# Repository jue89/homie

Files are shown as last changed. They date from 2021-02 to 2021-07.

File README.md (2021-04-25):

# Homie

Homie is an attempt to create wired smart-home devices.
Those devices are connected using [DOSE](https://api.riot-os.org/group__drivers__dose.html).

## Bus Interface

Every device has two *4P4C* jacks. This enables daisy-chaining the devices into one serial bus. The first and last device have to be terminated using a 120Ω resistor.

The bus interface:

| Pin | Description |
| --- | --- |
| 1 | GND |
| 2 | CAN LOW |
| 3 | CAN HIGH |
| 4 | +5V |

## Debug Interface

The debug interface features:
- Accessing board RESET and BOOT selector line
- Debug UART
- SWD Interface
- Power supply

The pin layout is designed to tolerate wrongly-connected pin header.

All data lines (SWDIO, SWCLK, RX, TX) hat to be protected against short-circuit on the debug port. (E.g. series resistors, ...)

| Description | Name  | Pin | Pin | Name  | Description |
| --- | :---: | :----: | :----: | :---: | --- |
| Selectes the boot mode. Pulled with a on-board resistor to the right level. | BOOT  |  **1** | **2**  | RX | Debug UART RX (Debug Adapter -> Board) |
| Voltage for all IO pins | VIO |  **3** | **4**  | TX | Debug UART TX (Board -> Debug Adapter) |
| | NC |  **5** | **6**  | VIN | Supply for the borad. The debug adapter has to protect this current direct using a diode. |
| SWD data line | SWDIO |  **7** | **8**  | SWCLK | SWD clock line |
| Board reset. Low active. | RESET |  **9** | **10** | GND | Ground |

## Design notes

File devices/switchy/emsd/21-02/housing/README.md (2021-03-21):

# Switchy Housing

This folder contains two versions of the housing:
- 3 switches
- 5 switches

Beside the PCB, you'll need to add:
- 3x or 5x switches with 16mm diameter and 3V LED
- 2x M3x2.7mm threaded inserts (eg. [3D Jake](https://www.3djake.de/3djake/gewindeeinsaetze-50er-set?sai=9419))
- 2x M3x10mm countersunk screw (eg. [Reichelt](https://www.reichelt.de/flach-senkkopfschrauben-kreuzschlitz-pzd-m3-10-mm-sks-m3x10-50-p65747.html))

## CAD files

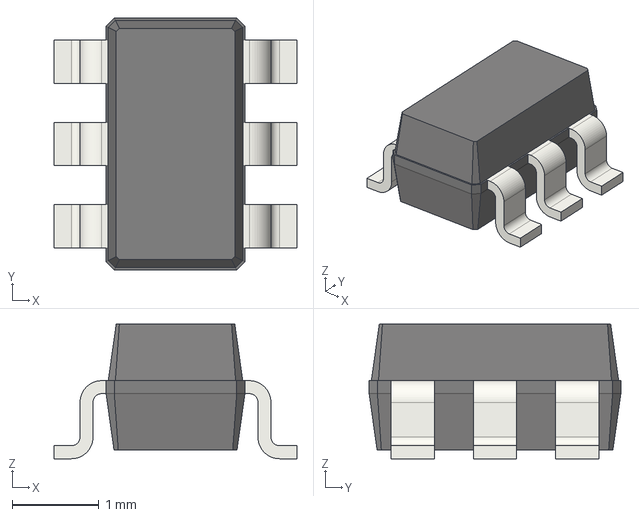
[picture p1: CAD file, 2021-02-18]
devices/flowr/pcb-iface/pool/3d_models/cache/6d752bc3-29b3-45df-8cf2-1e3aacefbcc6/3d_models/ic/so/SOT-23-6.step
2.80 x 2.90 x 1.55 mm

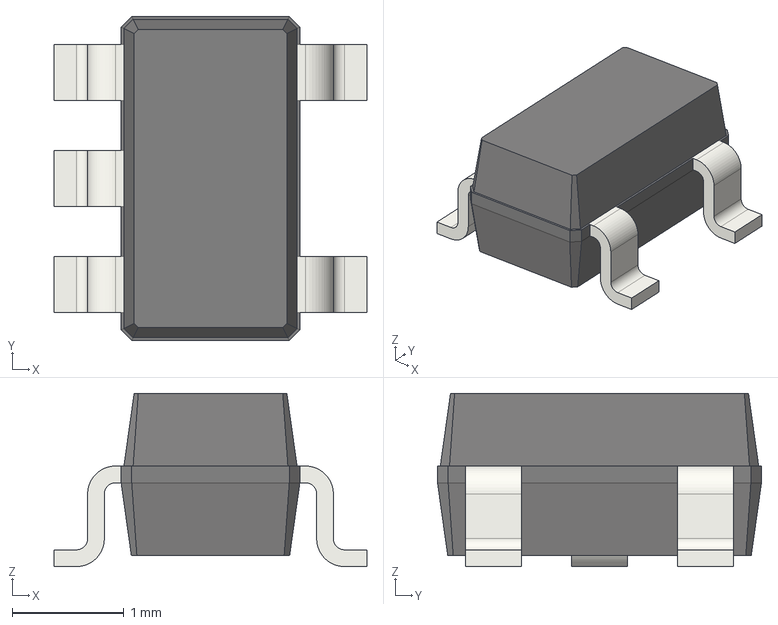
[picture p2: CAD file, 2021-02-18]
devices/flowr/pcb-iface/pool/3d_models/cache/6d752bc3-29b3-45df-8cf2-1e3aacefbcc6/3d_models/ic/SOT-23-5.step
2.80 x 2.90 x 1.55 mm

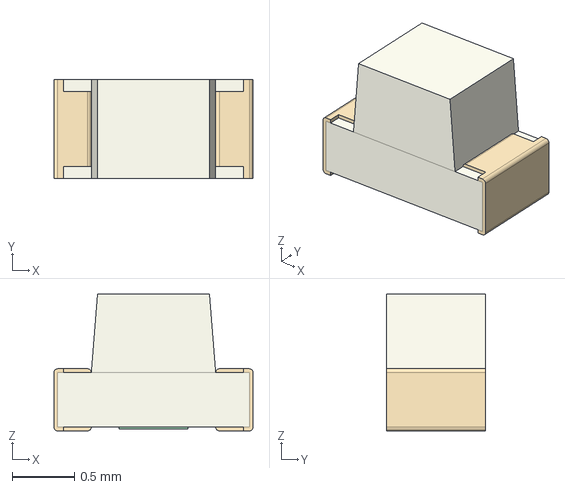
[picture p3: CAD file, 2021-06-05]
devices/flowr/pcb-iface/pool/3d_models/cache/6d752bc3-29b3-45df-8cf2-1e3aacefbcc6/3d_models/opto/LED_0603_1608Metric.step
1.60 x 0.8 x 1.10 mm

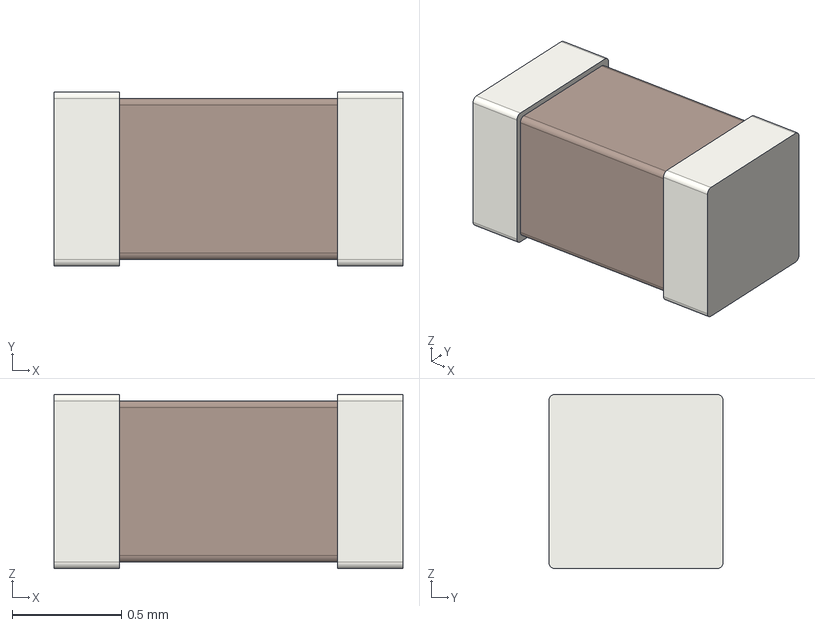
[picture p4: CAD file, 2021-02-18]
devices/flowr/pcb-iface/pool/3d_models/cache/6d752bc3-29b3-45df-8cf2-1e3aacefbcc6/3d_models/passive/capacitor/C_0603_1608Metric.step
1.60 x 0.8 x 0.8 mm

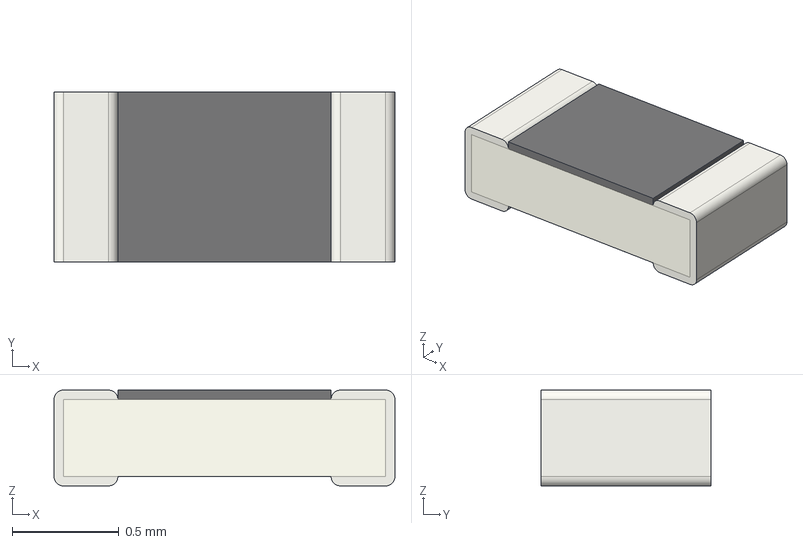
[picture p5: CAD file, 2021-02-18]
devices/flowr/pcb-iface/pool/3d_models/cache/6d752bc3-29b3-45df-8cf2-1e3aacefbcc6/3d_models/passive/resistor/R_0603_1608Metric.step
1.60 x 0.8 x 0.45 mm

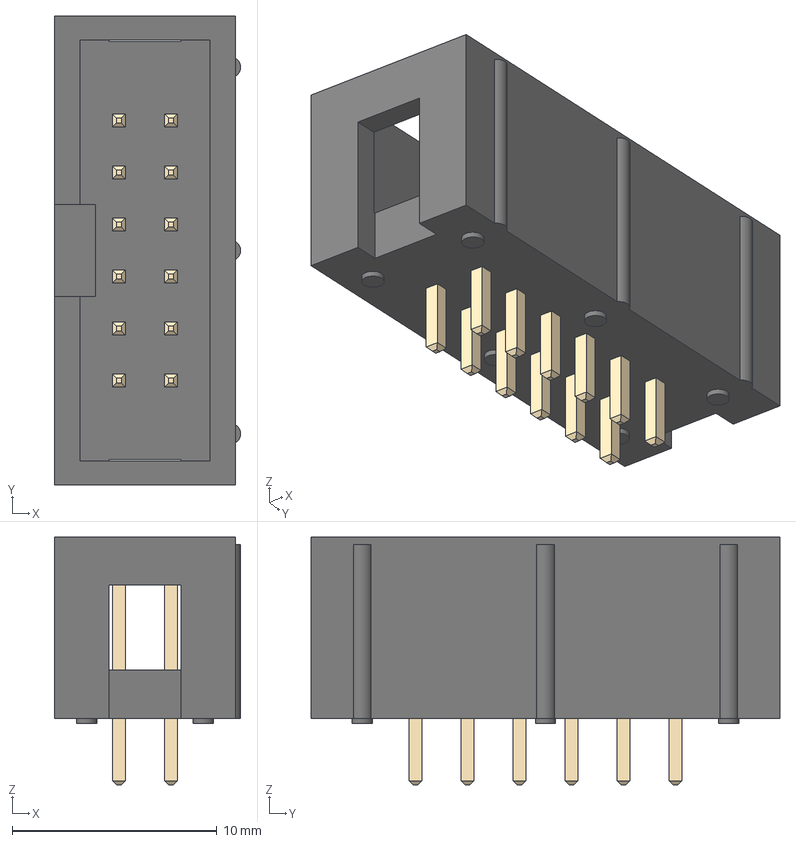
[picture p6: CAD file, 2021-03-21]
devices/picap/pcb/pool/3d_models/cache/6d752bc3-29b3-45df-8cf2-1e3aacefbcc6/3d_models/connector/header-idc/2.54mm/IDC-Header_2x06_P2.54mm_Vertical.step
9.10 x 22.9 x 12.1 mm

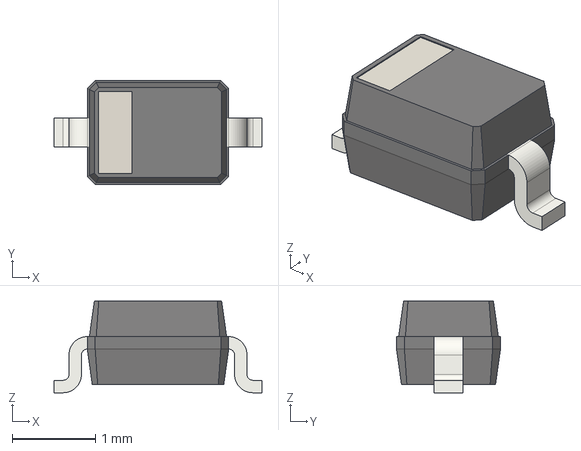
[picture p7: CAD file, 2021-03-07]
devices/relay/pcb/pool/3d_models/cache/6d752bc3-29b3-45df-8cf2-1e3aacefbcc6/3d_models/diode/D_SOD-323.step
2.50 x 1.25 x 1.10 mm

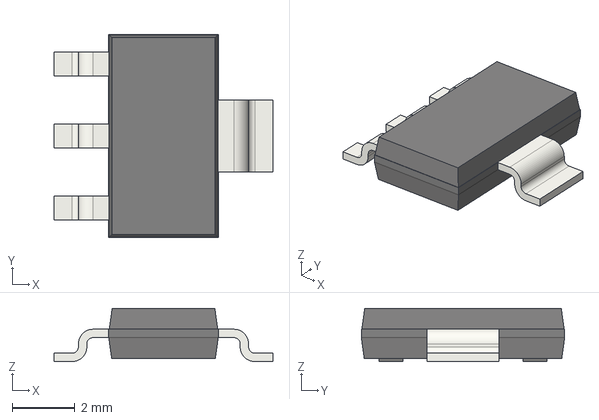
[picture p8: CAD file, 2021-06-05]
devices/relay/pcb/pool/3d_models/cache/6d752bc3-29b3-45df-8cf2-1e3aacefbcc6/3d_models/ic/so/SOT-223.step
7.00 x 6.50 x 1.70 mm

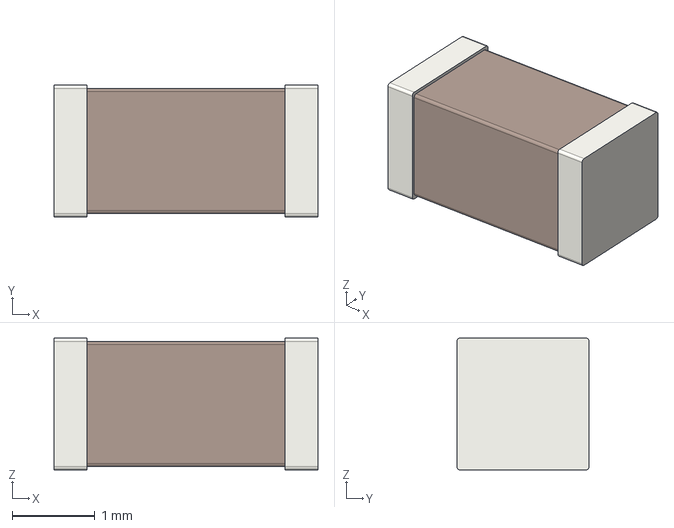
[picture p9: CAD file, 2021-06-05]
devices/relay/pcb/pool/3d_models/cache/6d752bc3-29b3-45df-8cf2-1e3aacefbcc6/3d_models/passive/capacitor/C_1206_3216Metric.step
3.20 x 1.60 x 1.60 mm

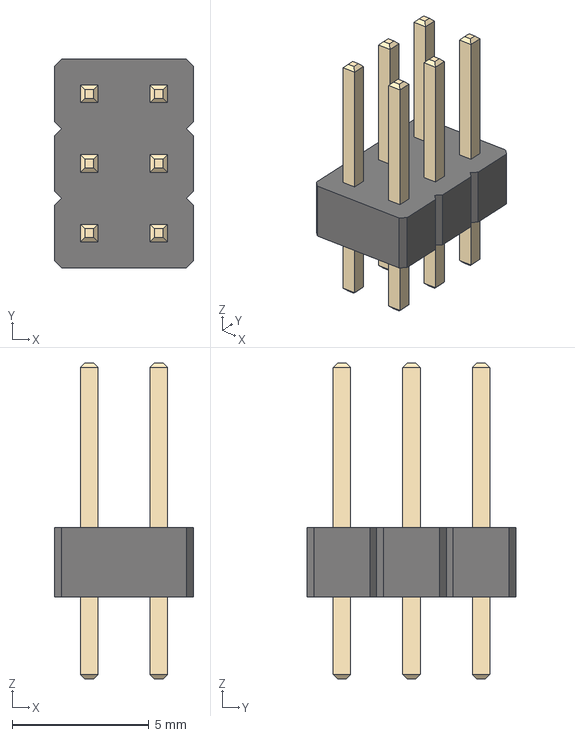
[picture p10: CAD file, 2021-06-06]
devices/switchy-rgb/pcb/pool/3d_models/cache/6d752bc3-29b3-45df-8cf2-1e3aacefbcc6/3d_models/connector/header/2.54mm/PinHeader_2x03_P2.54mm_Vertical.step
5.08 x 7.62 x 11.5 mm

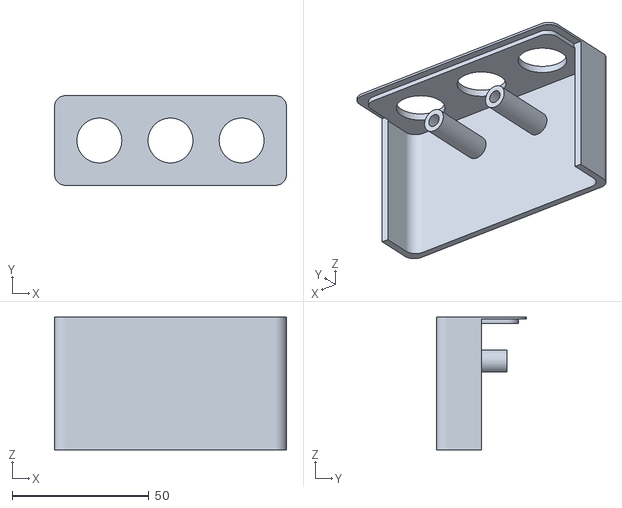
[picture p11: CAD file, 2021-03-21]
devices/switchy/emsd/21-02/housing/3front.stl
84.8 x 32.8 x 48.6

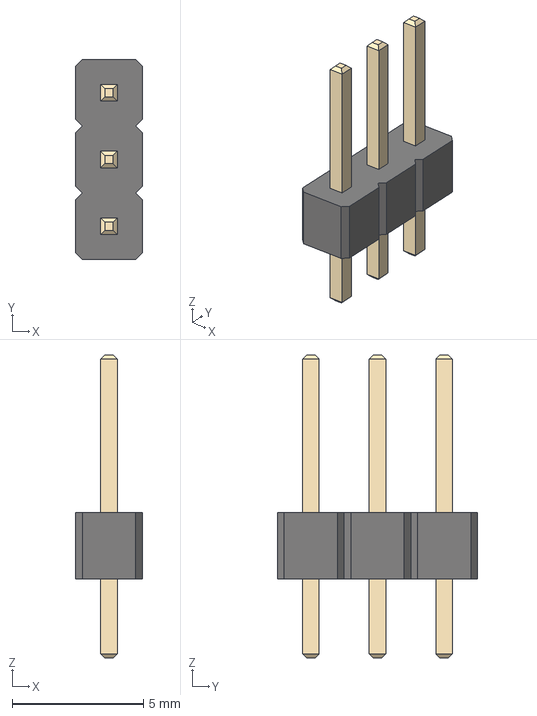
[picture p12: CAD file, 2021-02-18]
devices/switchy/pcb/pool/3d_models/cache/6d752bc3-29b3-45df-8cf2-1e3aacefbcc6/3d_models/connector/header/2.54mm/PinHeader_1x03_P2.54mm_Vertical.step
2.54 x 7.62 x 11.5 mm

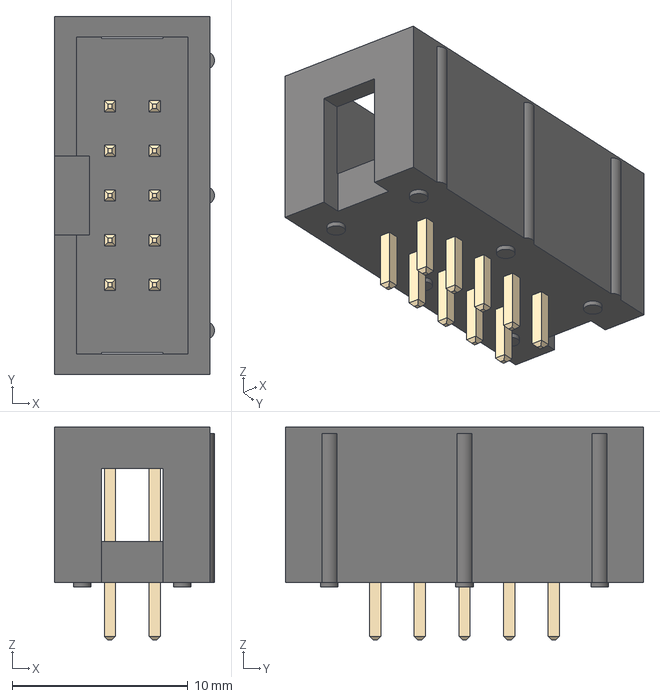
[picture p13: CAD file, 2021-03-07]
tools/prog/pcb/cache/3d_models/pool_6d752bc3-29b3-45df-8cf2-1e3aacefbcc6/3d_models/connector/header-idc/2.54mm/IDC-Header_2x05_P2.54mm_Vertical.step
9.10 x 20.4 x 12.1 mm

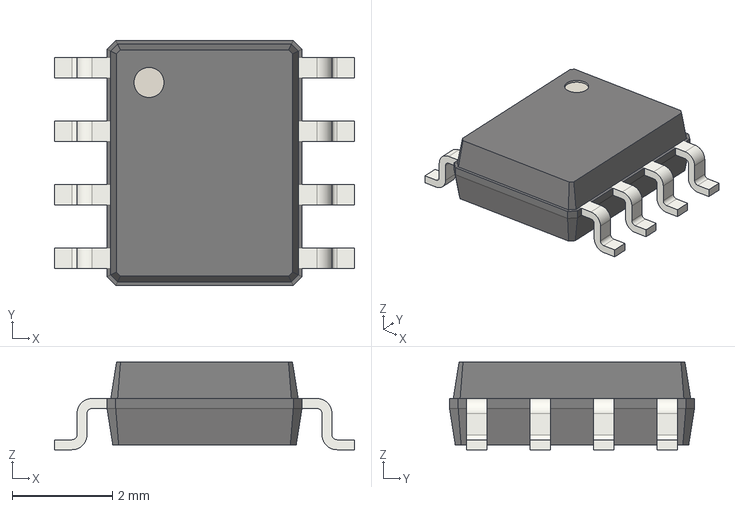
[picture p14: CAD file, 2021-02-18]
devices/flowr/pcb-iface/pool/3d_models/cache/6d752bc3-29b3-45df-8cf2-1e3aacefbcc6/3d_models/ic/so/SOIC-8_3.9x4.9mm_P1.27mm.step
6.00 x 4.90 x 1.75 mm

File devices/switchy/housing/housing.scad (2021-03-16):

$fn = 50;

module body (w, h, d) {
    radius = 4;
    linear_extrude (height = d, center = true) hull () {
        translate([w / 2 - radius, h / 2 - radius, 0]) circle(r = radius);
        translate([w / -2 + radius, h / 2 - radius, 0]) circle(r = radius);
        translate([w / 2 - radius, -h / 2 + radius, 0]) circle(r = radius);
        translate([w / -2 + radius, -h / 2 + radius, 0]) circle(r = radius);
    };
}

module half (h, w, d, wall, gap) {
    union() {
        difference () {
            // Outer shell
            body(w = w + 2 * wall, h = h + 2 * wall, d = d + 2 * wall);
            
            // Inner body
            translate([0, 0, -wall])
                body(w = w, h = h, d = d + 2 * wall);
            
            // Cut in two
            translate([0, (h + wall) / 2, -(wall/2) + gap])
                cube([w + 5 * wall, h + wall, d + 2 * wall], center = true);
            
            // Housing lip
            translate([0, 0, - d / 2 - wall])
                cube([w + 5 * wall, h + 3 * wall, wall], center = true);
        };
        
        // Housing lip
        translate([0, 0, d / 2 + wall / 2])
            body(w = w - gap * 2, h = h - gap * 2, d = wall);
    };
}

N = 1; // Button Count = N * 2 + 1
pitch = 26; // Distance between two buttons
wall = 2.4; // Wall thinksness
wallgap = 0.4;
height = 28; // Inner height
depth = 45; // Inner depth
width = 2 * N * pitch + height; // Inner widht
lpheight = 1.65; // Height of PCB
screws = [ // Screw positions measured from housing center
    [-pitch/2, -depth/2 - wall + 23 + 10.67],
    [pitch/2, -depth/2 - wall + 23 + 10.67]
];
screwh1 = (height - 16.68) / 2 - 1 - lpheight; // Hight of dome 1
screwh2 = height - screwh1 - lpheight; // Hight of dome 2
screwhole = 3.5; // Diameter of screw hole
screwhead = 5.8; // Diameter of screw head
ruthexd=4.4; // Ruthex diameter
ruthexh=7; // Ruthex height
switchd=16.4; // Switch diameter
ifaceh=16; // Bus interface height
ifacew=12; // Bus interface width

module sink_hole() {
    depth=2;
    expansion=10;
    angle=45;
    rotate([-90, 0, 0]) translate([0, 0, -depth]) rotate_extrude(convexity = 10) polygon(points=[
        [0, expansion],
        [screwhead/2, expansion],
        [screwhead/2, 0],
        [screwhole/2, -(screwhead/2 - screwhole/2) / tan(angle)],
        [screwhole/2, -expansion],
        [0, -expansion]
    ]);
}

module front () {
    union() {
        difference () {
            // Housing half
            half(w = width, h = height, d = depth, wall = wall, gap = wallgap);
            
            // - Breakout for switches
            for (i = [-N : N]) {
                translate([i * pitch, 0, 0])
                    cylinder(h = depth, d = switchd);
            }
        }
        for (p = screws) {
            translate([0, screwh2 - height / 2, 0]) difference() {
                // Dome
                translate([p[0], 0, p[1]]) rotate([90, 0, 0]) cylinder(h=screwh2, d=8);
                
                // - Ruthex pocket
                translate([p[0], 1, p[1]]) rotate([90, 0, 0]) cylinder(h=ruthexh+1, d=ruthexd);
                
                // - Screw hole
                translate([p[0], 2, p[1]]) rotate([90, 0, 0]) cylinder(h=screwh2+1, d=screwhole);
            }
        };
    }
};

module back () {
    difference() {
        union() {
            difference () {
                // Body
                rotate([0, 180, 180]) half(w = width, h = height, d = depth, wall = wall, gap = wallgap);
                
                // - Bus ports
                translate([-pitch / 2, 0, -depth / 2]) cube([ifacew, ifaceh, depth], center = true);
                translate([pitch / 2, 0, -depth / 2]) cube([ifacew, ifaceh, depth], center = true);
            };
            
            // Domes
            for (p = screws) {
                translate([p[0], height / 2, p[1]]) rotate([90, 0, 0]) cylinder(h=screwh1, d=8);
            };
        };
        
        // - Holes
        for (p = screws) {
            // Screw
            translate([p[0], height / 2 + wall, p[1]]) sink_hole();
        };
    }
}

front();
back();

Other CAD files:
devices/switchy/emsd/21-02/housing/3back.stl
devices/switchy/emsd/21-02/housing/5back.stl
devices/flowr/pcb-iface/pool/3d_models/cache/6d752bc3-29b3-45df-8cf2-1e3aacefbcc6/3d_models/connector/modular/te/5555980-1.step
devices/switchy/emsd/21-02/housing/5front.stl

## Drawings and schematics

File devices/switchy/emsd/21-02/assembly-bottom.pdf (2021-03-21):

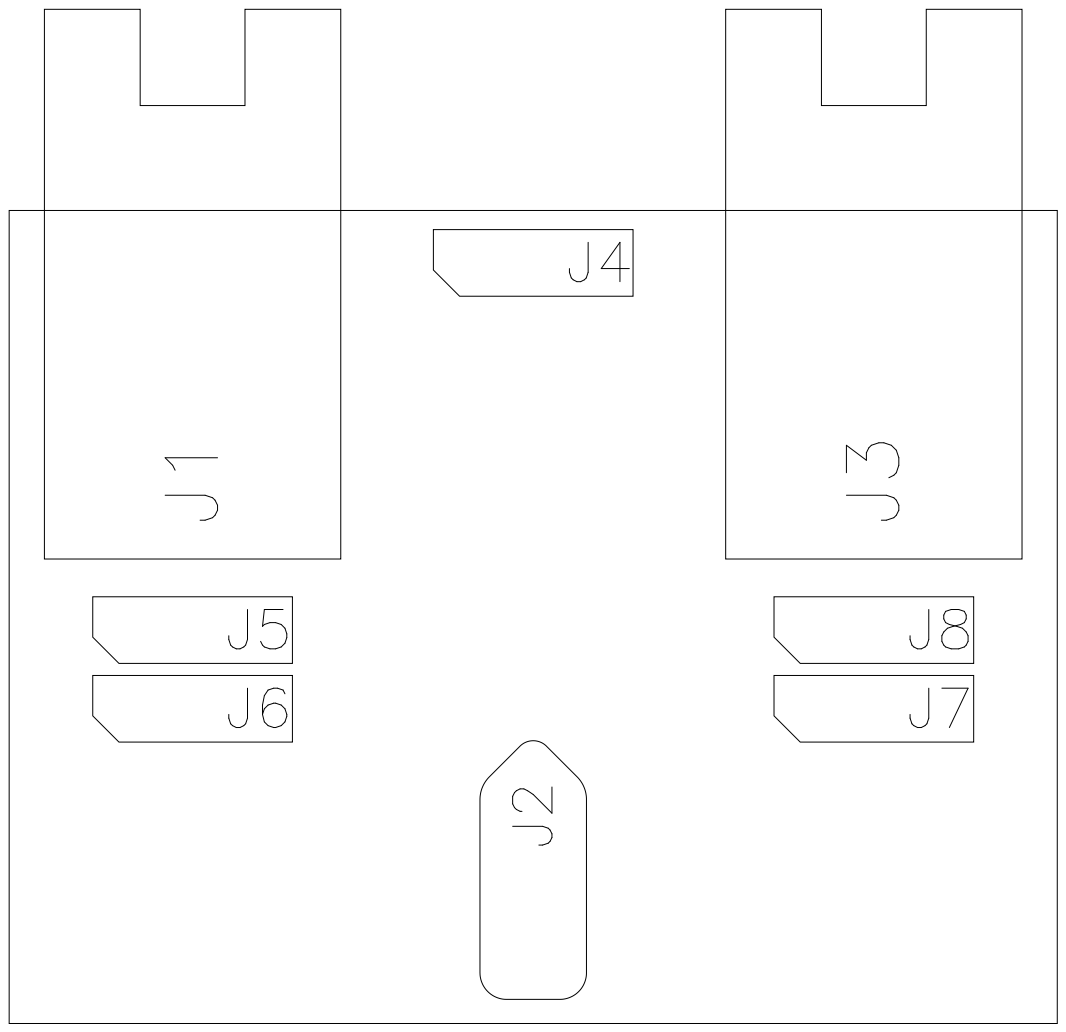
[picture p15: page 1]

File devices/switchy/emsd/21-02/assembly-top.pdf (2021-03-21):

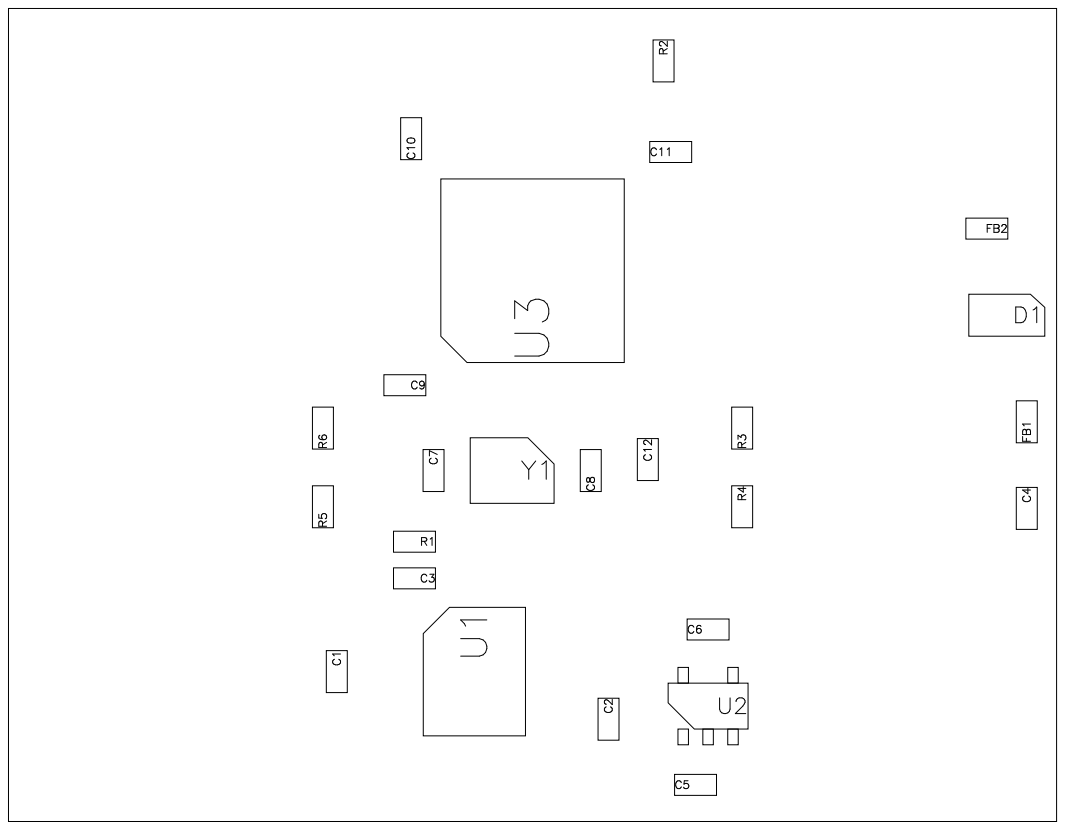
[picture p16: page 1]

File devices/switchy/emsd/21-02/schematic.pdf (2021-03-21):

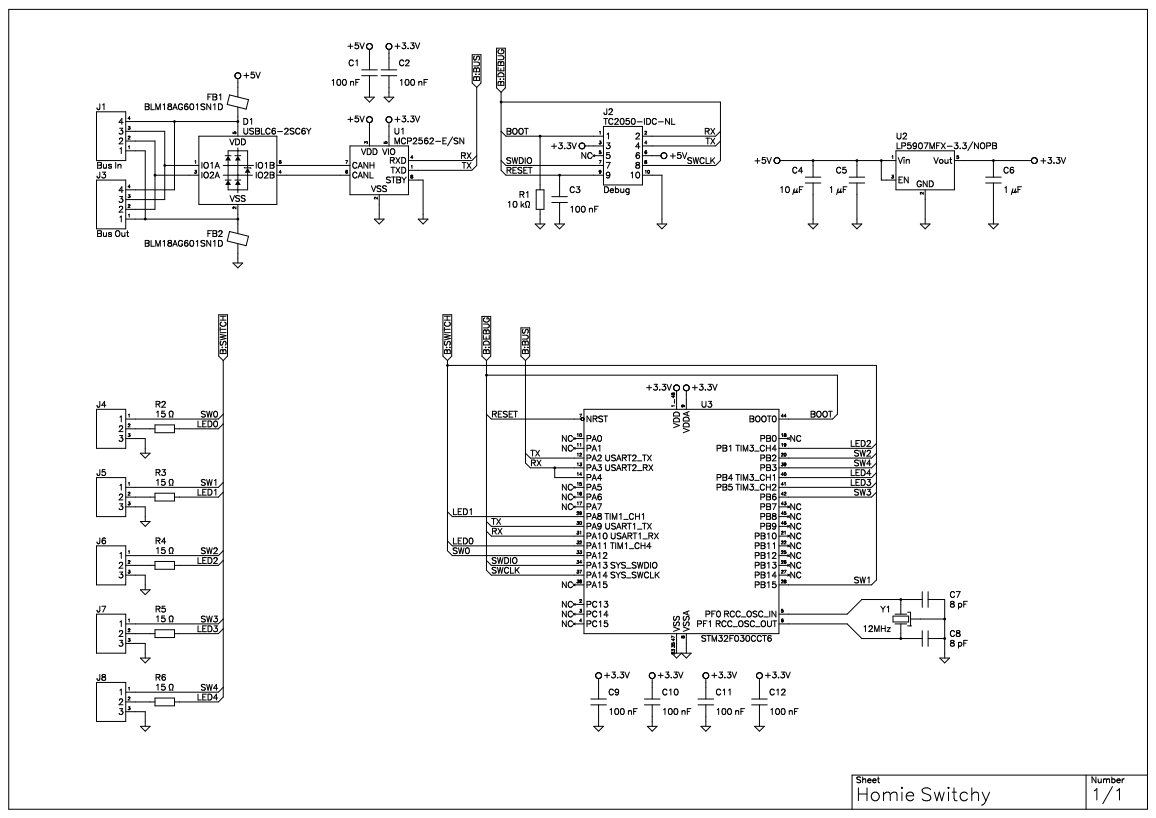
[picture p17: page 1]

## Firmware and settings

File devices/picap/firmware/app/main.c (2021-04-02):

#include <stdio.h>
#include "net/netdev.h"
#include "net/gnrc/pktbuf.h"
#include "msg.h"
#include "thread.h"
#include "dose.h"
#include "dose_params.h"
#include "stdio_uart.h"
#include "ethos.h"
#include "ztimer.h"
#include "periph/gpio.h"
#include "periph/wdt.h"
#include "ps.h"
#include "fmt.h"

#define BRIDGE_MSG_TYPE_EVENT (0x4321)
#define BRIDGE_MSG_TYPE_PACKET (0x4322)
#define RCV_QUEUE_SIZE (32)
#define LED_TIME_USEC (50000)
#define WDT_TIME_MS (20000)

typedef struct {
    netdev_t * dev;
    kernel_pid_t pid;
    kernel_pid_t peer;
    char stack[THREAD_STACKSIZE_DEFAULT];
    gpio_t led;
    ztimer_t led_timer;
} bridge_port_t;

static void _event_cb(netdev_t *dev, netdev_event_t event)
{
    bridge_port_t *port = dev->context;

    if (event == NETDEV_EVENT_ISR) {
        /* Called from IRQ context -> send message to port thread */
        msg_t msg = { .type = BRIDGE_MSG_TYPE_EVENT, .content = { .ptr = dev } };
        if (msg_try_send(&msg, port->pid) <= 0) {
            puts("_event_cb: possibly lost interrupt.");
        }
    }
    else if (event == NETDEV_EVENT_RX_COMPLETE) {
        /* Called from port context */
        int bytes_expected;
        int bytes_read;
        gnrc_pktsnip_t *pkt;
        msg_t msg;

        /* Fetch byte count of the received packet */
        bytes_expected = dev->driver->recv(dev, NULL, 0, NULL);
        if (bytes_expected <= 0) return;

        /* Store received packet */
        pkt = gnrc_pktbuf_add(NULL, NULL, bytes_expected, GNRC_NETTYPE_UNDEF);
        if (!pkt) {
            puts("_event_cb: cannot allocate pktsnip.");
            /* drop the packet */
            dev->driver->recv(dev, NULL, bytes_expected, NULL);
            return;
        }

        bytes_read = dev->driver->recv(dev, pkt->data, bytes_expected, NULL);
        if (bytes_read <= 0) {
            gnrc_pktbuf_release(pkt);
            puts("_event_cb: empty packet.");
            return;
        }
        if (bytes_read < bytes_expected) {
            /* we've got less than the expected packet size,
             * so free the unused space.*/
            puts("_event_cb: reallocating.");
            printf("%d\n", bytes_read);
            gnrc_pktbuf_realloc_data(pkt, bytes_read);
        }

        msg.type = BRIDGE_MSG_TYPE_PACKET;
        msg.content.ptr = (void*) pkt;
        if (msg_try_send(&msg, port->peer) <= 0) {
            gnrc_pktbuf_release(pkt);
            puts("_event_cb: lost packet.");
        }
    }
    else if (event == NETDEV_EVENT_TX_COMPLETE) {
	    /* NOP */
    }
    else {
        printf("_event_cb: warning: unhandled event %u.\n", event);
    }
}

static void _gpio_clear(void *args)
{
    gpio_t * gpio = (gpio_t *) args;
    gpio_clear(*gpio);
}

static void *_port_thread(void *args)
{
    int rc;
    msg_t queue[RCV_QUEUE_SIZE];
    bridge_port_t *port = args;
    netopt_enable_t en = NETOPT_ENABLE;

    /* Prepare IPC */
    msg_init_queue(queue, RCV_QUEUE_SIZE);

    /* Setup netdev */
    port->dev->event_callback = _event_cb;
    rc = port->dev->driver->init(port->dev);
    port->dev->driver->set(port->dev, NETOPT_PROMISCUOUSMODE, &en, sizeof(en));
    if (rc < 0) {
        return NULL;
    }

    /* Setup LED */
    gpio_init(port->led, GPIO_OUT);
    port->led_timer.callback = _gpio_clear;
    port->led_timer.arg = &port->led;

    /* Store own PID */
    port->pid = thread_getpid();

    while (1) {
        msg_t msg;
        msg_receive(&msg);
#if IS_ACTIVE(MODULE_PERIPH_WDT)
        wdt_kick();
#endif
        if (msg.type == BRIDGE_MSG_TYPE_EVENT) {
            /* Some event occured at the driver */
            port->dev->driver->isr(port->dev);
        }
        else if (msg.type == BRIDGE_MSG_TYPE_PACKET) {
            /* Got a message from peer port */
            ztimer_remove(ZTIMER_USEC, &port->led_timer);
            gpio_set(port->led);
            ztimer_set(ZTIMER_USEC, &port->led_timer, LED_TIME_USEC);

            gnrc_pktsnip_t *pkt = msg.content.ptr;
            port->dev->driver->send(port->dev, (iolist_t*) pkt);
            gnrc_pktbuf_release(pkt);
        }
    }

    return NULL;
}

void bridge_port_init (bridge_port_t *port, netdev_t *dev, const char * name, gpio_t led)
{
    int rc;

    port->dev = dev;
    port->pid = KERNEL_PID_UNDEF;
    port->peer = KERNEL_PID_UNDEF;
    port->led = led;
    dev->context = port;

    rc = thread_create(port->stack, sizeof(port->stack),
                       THREAD_PRIORITY_MAIN - 1, THREAD_CREATE_STACKTEST,
                       _port_thread, (void*) port, name);
    (void)rc;
    assert(rc > 0);
}

void bridge_port_connect (bridge_port_t *a, bridge_port_t *b)
{
    a->peer = b->pid;
    b->peer = a->pid;
}

static uint8_t ethos_inbuf[2048];
static const ethos_params_t ethos_params = {
    .uart = STDIO_UART_DEV,
    .baudrate = STDIO_UART_BAUDRATE,
    .buf = ethos_inbuf,
    .bufsize = sizeof(ethos_inbuf)
};

static dose_t dose;
static bridge_port_t dose_port;
ethos_t ethos;
static bridge_port_t ethos_port;

int main (void)
{
    puts("Start WDT");
#if IS_ACTIVE(MODULE_PERIPH_WDT)
    wdt_setup_reboot(0, WDT_TIME_MS);
    wdt_start();
#endif

    puts("Setup netifs");
    dose_setup(&dose, &dose_params[0], 0);
    ethos_setup(&ethos, &ethos_params);

    puts("Setup ports");
    bridge_port_init(&dose_port, (netdev_t*) &dose, "dose", LED_TX_GPIO_PIN);
    bridge_port_init(&ethos_port, (netdev_t*) &ethos, "ethos", LED_RX_GPIO_PIN);

    puts("Connect ports");
    bridge_port_connect(&dose_port, &ethos_port);

    while (1) {
        ztimer_sleep(ZTIMER_USEC, 10000000);
#if IS_ACTIVE(MODULE_PS)
	ps();
#endif
    }

    return 0;
}

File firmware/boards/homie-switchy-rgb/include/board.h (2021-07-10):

/*
 * Copyright (C) 2021 Jue
 *
 * This file is subject to the terms and conditions of the GNU Lesser
 * General Public License v2.1. See the file LICENSE in the top level
 * directory for more details.
 */

/**
 * @ingroup     boards_homie-switchy-rgb
 * @{
 *
 * @file
 * @brief       Board specific definitions for the homie-switchy-rgb
 *
 * @author      Jue <me@jue.yt>
 */

#ifndef BOARD_H
#define BOARD_H

#include "cpu.h"
#include "periph_conf.h"
#include "periph_cpu.h"

#ifdef __cplusplus
extern "C" {
#endif

#define STDIO_UART_DEV               UART_DEV(0)

#define XTIMER_WIDTH        (16)
#define XTIMER_BACKOFF      (19)

#define CONFIG_ZTIMER_USEC_DEV       TIMER_DEV(0)
#define CONFIG_ZTIMER_USEC_WIDTH     (16)
#define CONFIG_ZTIMER_USEC_BASE_FREQ MHZ(1)

#define DOSE_PARAM_UART              UART_DEV(1)
#define DOSE_PARAM_SENSE_PIN         GPIO_PIN(PORT_A, 4)
//#define DOSE_PARAM_BAUDRATE          MHZ(1)

#define DOSE_PARAM_UART              UART_DEV(1)
#define DOSE_PARAM_SENSE_PIN         GPIO_PIN(PORT_A, 4)

#define SW0_BTN_GPIO_PIN             GPIO_PIN(PORT_A, 3)
#define SW0_LED_R_PWM_DEV            PWM_DEV(3)
#define SW0_LED_R_PWM_CH             (1)
#define SW0_LED_G_PWM_DEV            PWM_DEV(3)
#define SW0_LED_G_PWM_CH             (0)
#define SW0_LED_B_PWM_DEV            PWM_DEV(3)
#define SW0_LED_B_PWM_CH             (2)

#define SW1_BTN_GPIO_PIN             GPIO_PIN(PORT_B, 1)
#define SW1_LED_R_PWM_DEV            PWM_DEV(1)
#define SW1_LED_R_PWM_CH             (2)
#define SW1_LED_G_PWM_DEV            PWM_DEV(1)
#define SW1_LED_G_PWM_CH             (1)
#define SW1_LED_B_PWM_DEV            PWM_DEV(1)
#define SW1_LED_B_PWM_CH             (0)

#define SW2_BTN_GPIO_PIN             GPIO_PIN(PORT_B, 10)
#define SW2_LED_R_PWM_DEV            PWM_DEV(4)
#define SW2_LED_R_PWM_CH             (1)
#define SW2_LED_G_PWM_DEV            PWM_DEV(4)
#define SW2_LED_G_PWM_CH             (0)
#define SW2_LED_B_PWM_DEV            PWM_DEV(0)
#define SW2_LED_B_PWM_CH             (2)

#define SW3_BTN_GPIO_PIN             GPIO_PIN(PORT_C, 8)
#define SW3_LED_R_PWM_DEV            PWM_DEV(0)
#define SW3_LED_R_PWM_CH             (0)
#define SW3_LED_G_PWM_DEV            PWM_DEV(0)
#define SW3_LED_G_PWM_CH             (1)
#define SW3_LED_B_PWM_DEV            PWM_DEV(4)
#define SW3_LED_B_PWM_CH             (2)

#define SW4_BTN_GPIO_PIN             GPIO_PIN(PORT_B, 5)
#define SW4_LED_R_PWM_DEV            PWM_DEV(2)
#define SW4_LED_R_PWM_CH             (2)
#define SW4_LED_G_PWM_DEV            PWM_DEV(2)
#define SW4_LED_G_PWM_CH             (1)
#define SW4_LED_B_PWM_DEV            PWM_DEV(2)
#define SW4_LED_B_PWM_CH             (0)

/**
 * @brief   Initialize board specific hardware
 */
void board_init(void);

#ifdef __cplusplus
}
#endif

#endif /* BOARD_H */
/** @} */

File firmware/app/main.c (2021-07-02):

#include <stdio.h>
#include "hdp.h"
#include "shell.h"
#include "shell_commands.h"
#include "net/gnrc/pktdump.h"
#include "net/gnrc.h"
#if IS_ACTIVE(MODULE_FREQUENCY_COUNTER)
#include "frequency_counter.h"
#endif

static const hdp_params_t hdp_params = HDP_PARAMS_INIT;
static hdp_ctx_t hdp_ctx;

int main(void)
{
#if IS_ACTIVE(MODULE_FREQUENCY_COUNTER)
    frequency_counter_init();
#endif

    hdp_init(&hdp_ctx, &hdp_params);

    char line_buf[SHELL_DEFAULT_BUFSIZE];
    shell_run(NULL, line_buf, SHELL_DEFAULT_BUFSIZE);

    return 0;
}

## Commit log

2021-02-15 Add device template
2021-02-18 template: fix power net for bus interface
2021-02-18 switchy: initial commit
    [C_0603_1608Metric.step, PinHeader_1x03_P2.54mm_Vertical.step, R_0603_1608Metric.step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]
2021-02-20 template/pcb: add Aisler rules and stackup
2021-02-20 switchy/psb: rearranged schematic
2021-02-20 template/pcb: revised bus interface
2021-02-20 template/pcb/sch: display pin names for connectors
2021-02-21 switchy: add housing model
    [housing.scad]
2021-02-22 switchy/housing: fix screw positions
    [housing.scad]
2021-02-22 switchy/housing: adjust width an depth
    [housing.scad]
2021-03-07 switchy/housing: improved model after frist test print
    [housing.scad]
2021-03-07 switchy/pcb: last changes
    [5555980-1.step, C_0603_1608Metric.step, PinHeader_1x03_P2.54mm_Vertical.step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]
2021-03-07 switchy: add gerber sent to factory
    [switchy.drills_pth.xln, switchy.holes_npth.xln]
2021-03-07 prog: initial PCB project
    [C_0603_1608Metric.step, D_SOD-323.step, IDC-Header_2x05_P2.54mm_Vertical.step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]
2021-03-07 prog: add gerber sent to factory
    [programmer.drills_pth.xln, programmer.holes_npth.xln]
2021-03-07 template/pcb: upgrade to new Horizon project pool
2021-03-16 switchy/housing: improved model after unsuccessful print
    [housing.scad]
2021-03-21 switchy/fw: add board config and hello world app
2021-03-21 prog/pcb: fix debug header silkscreen
2021-03-21 switchy/emsd: add housing
    [3back.stl, 3front.stl, 5back.stl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]
2021-03-21 switchy/emsd: add service info
2021-03-21 picap: initial commit
    [5555980-1.step, C_0603_1608Metric.step, IDC-Header_2x06_P2.54mm_Vertical.step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]
2021-03-27 prog/pcb: reroute debug interface for more clearance
2021-03-27 picap/firmware: add board
2021-03-28 picap/firmware: fix LED pin definition
    [board.h]
2021-04-02 picap/schematic: fix RX/TX LEDs
2021-04-04 switchy/firmware: increase delay before programming
    Sometimes the uC isn't booted fast enough. So add 100ms waiting time after the released reset.
2021-04-04 Switch to experimental saul_observer RIOT
2021-04-05 switchy/firmware: fix Menuconfig for clock config
2021-04-05 switchy/firmware: make board configurable using Menuconfig
2021-04-10 firmware/hdp: allow publishing state of selected SAUL devices
2021-04-11 switchy/firmware: bring BTN and LED into right order
2021-04-11 firmware/hdp: set thread prio 1 lower than UDP
    A prio that's too low leads to dead locks due to priority inversion.
    [hdp.h]
2021-04-20 firmware/dimmable_led: switch to uint16_t gamma correction LUT
    [board.c, dimmable_led.c]
2021-04-20 pwmctrl/firmware: add board definition
2021-04-25 devices: updated template
2021-04-25 devices: support for multiple templates
2021-04-25 devices: add ISO template
2021-06-05 device: update basic template
2021-06-05 devices: update ISO template
2021-06-05 picap: update schematic and PCB
    [5555980-1.step]
2021-06-05 relay: initial commit
    [5555980-1.step, C_0603_1608Metric.step, C_1206_3216Metric.step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]
2021-06-05 relay: add board file
2021-06-05 relay: add basic app
2021-06-06 switchy-rgb: initial commit
    [5555980-1.step, C_0603_1608Metric.step, PinHeader_2x03_P2.54mm_Vertical.step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]
2021-06-06 switchy-rgb: add fabrication data for JLC
    [switchy-rgb.GBL, switchy-rgb.GBO, switchy-rgb.GBS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]
2021-06-06 flowr: add sense PCB
    [C_0603_1608Metric.step, LED_0603_1608Metric.step, R_0603_1608Metric.step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]
2021-06-06 flowr: add sense EMSD for JLC
    [flowr-sense-jlc.gbl, flowr-sense-jlc.gbo, flowr-sense-jlc.gbp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]
2021-07-01 switchy: move app and board to common dir
2021-07-01 switchy: include header files of saul devices only if needed
2021-07-01 relay: move app and board to common dir
2021-07-01 pwmctrl: move app and board to common dir
2021-07-01 flowr: add iface PCB
    [5555980-1.step, C_0603_1608Metric.step, LED_0603_1608Metric.step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]
2021-07-01 firmware/hdp: workaround for NanoCBOR bug
    Cf. https://github.com/bergzand/NanoCBOR/pull/55
    [hdp_pkt.c]
2021-07-02 firmware: add frequency counter driver
2021-07-02 flowr: add board defintion
2021-07-02 flowr: add firmware
2021-07-02 relay: fix channel names
    [board.h]
2021-07-10 dimmable_led: add invert option
    [dimmable_led.c]
2021-07-10 switchy: fade LEDs fast
2021-07-10 switchy-rgb: add board file
2021-07-10 switchy-rgb: add firmware
2021-07-10 dimmable_led: track initialized devs and don't init them a 2nd time
2021-07-11 picap: reduce baudrate for host device
    Otherwise the host may overwhelm the MCU.
2021-11-20 relay: add hosríng for a mains relay
2021-11-21 relay: improve housing model
2021-12-17 relay: bump quickbox version
2021-12-28 relay/houring: remove notch from power connector
    This allows for support-less printing

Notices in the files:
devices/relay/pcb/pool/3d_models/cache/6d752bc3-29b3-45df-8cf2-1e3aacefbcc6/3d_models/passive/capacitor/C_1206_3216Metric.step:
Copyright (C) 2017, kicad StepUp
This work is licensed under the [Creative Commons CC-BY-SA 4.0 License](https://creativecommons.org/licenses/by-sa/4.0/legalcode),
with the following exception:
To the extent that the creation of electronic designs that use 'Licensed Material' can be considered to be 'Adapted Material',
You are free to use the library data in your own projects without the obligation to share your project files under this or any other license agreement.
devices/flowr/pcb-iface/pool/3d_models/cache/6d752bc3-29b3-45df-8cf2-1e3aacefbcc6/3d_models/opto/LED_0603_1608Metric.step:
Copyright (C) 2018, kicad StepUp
